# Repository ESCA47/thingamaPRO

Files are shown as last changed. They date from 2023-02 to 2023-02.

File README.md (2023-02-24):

# thingamaPRO

Order at your own risk, even i fuck up too often. Maybe poke at me for help but for the most part you are on your own if you do decide to order these.
This projecet was created to do the stupid thing I wanted and I got mine.

Goals of the project is to give as one to one a switch pro feel for ultimate on a gcc/phob interface. Anything past that is a nice bonus(melee or people calibrating to their own prefrences).

I highly implore you to calibrate either to the 3dp jig(and follow reccommended offsets or test for your own(except cstick that one is pretty bang on already)) or use some octo shell to calibrate before putting circle gates on these as otherwise the sticks will feel like dogshit and that's on you or whoever made you the thingamapro and you should yell at them.

Some things to absolutely not forget when ordering:

Front boards are 0.8mm thick and need gold finish to work at their best, ill probably chuck some of my bstock stuff for cheap on etsy if you dont want to drop 80 on 5 standard assembly boards

Main PCB is 1.2mm thick and you can do the regular finish as none are in the context of contact pads

Warnings aside the files I have supplied are only really a start since I personally dont want to say use this part or that part and tank the stuff i use over multiple designs so you will need a couple bit more brain cells to actually part out the boards properly. 

So for instance you will need to format the position file properly for jlc to be able to read it and also you need to double check all of the parts are on the right orientation(if someone wants to do this for me feel free since even i dont bother and i tinker with it too much). For the bom it should be descript enough that you can figure out the parts from looking at lcsc so have fun there.

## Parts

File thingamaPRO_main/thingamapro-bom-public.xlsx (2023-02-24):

Comment | Designator | Footprint | LCSC Part #（optional）
0.047u | C15 C16 C17 C18 C19 C20 | 0603_C | C1622
1u | C2 C13 | 0402_C
1u | C21 C31 C32 C33 | 0603_C
10u | C22 C23 | 0603_C | C19702
100n | C1 C9 C10 C11 | 0402_C
M7C | D1 | SOD-123 | C8598
1n4148 | D4 D5 D6 D7 | SOD-323
Schottky Barrier Diodes | D2, D8 | SOD-323 | C146335
Fuse | F1 | Fuse-1206 | C69680
Bottom Contact Surface Mount 0.5mm SMD,P=0.5mm FFC/FPC Connectors | J3
Shou Han Type-C 24P QCHT | J9 |  | C456013
Q_PMOS_GDS | Q1 | SOT-23 | C15127
Q_NMOS_GSD | Q2 Q3 | SOT-23 | C20917
10k | R1 R3 R5 | 0603_R | C25804
10k | R6 R7 R12 R13 | 0402_R
100R | R2 R4 | 0603_R | C22775
5.1k | R8 R9 | 0603_R
1K | R14 R19 | 0402_R
2k | R15 R16 R17 R18 | 0603_R | C22975
27R | R29, R30 | 0402_R
4pos smd switch 2.54mm 4 SMD-8P dip switch | sw1
Switch | S1 |  | C318884
MCP3002 | U6 U12 | SOIC-8
DRV5055A3QDBZR | U7 U8 U10 U11 | SOT-23
W25Q128JVS | U9 | SOIC-8
PRTR5V0U2X | U13 | SOT143B | C12333
XC6206PxxxMR | U14 | SOT-23 | C5446
RP2040 | U15 | RP2040-QFN-56 | C2040
12MHz SMD3213-3P | Y1 | Resonator_SMD_Murata_CSTxExxV-3Pin_3.0x1.1mm
6.3V 47uF | C3 | 3216

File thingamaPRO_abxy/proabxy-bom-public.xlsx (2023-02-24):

Comment | Designator | Footprint | LCSC Part #（optional）
Bottom Contact Surface Mount 0.5mm SMD,P=0.5mm FFC/FPC Connectors | J1
Switch | SW3, SW4, SW5, SW6
Clamshell 5 Double-sided Contact Surface Mount 0.5mm SMD,P=0.5mm FFC/FPC Connectors | J2
Bav70 | D1, D2

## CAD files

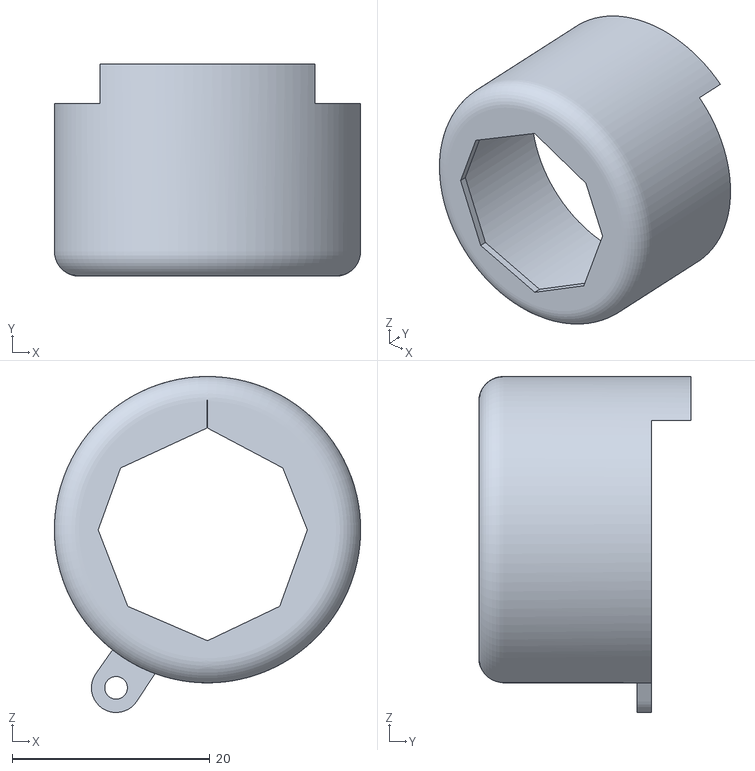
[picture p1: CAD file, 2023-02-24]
calibrationjig/mainjig.stl
31.0 x 21.5 x 34.0

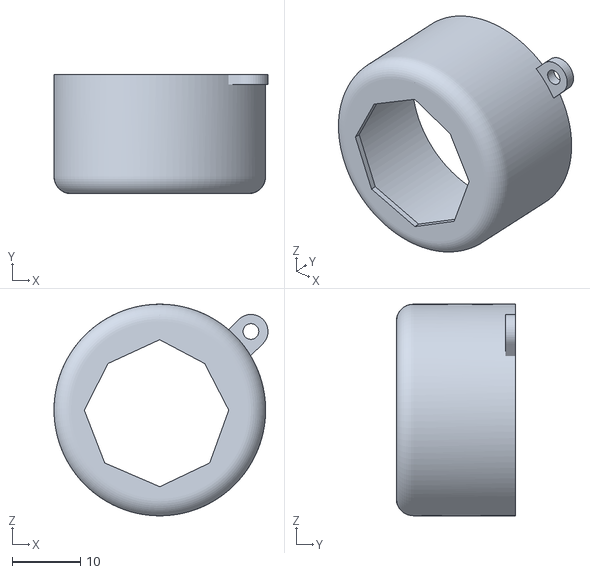
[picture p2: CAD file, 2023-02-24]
calibrationjig/cstickjig.stl
31.3 x 17.5 x 31.0

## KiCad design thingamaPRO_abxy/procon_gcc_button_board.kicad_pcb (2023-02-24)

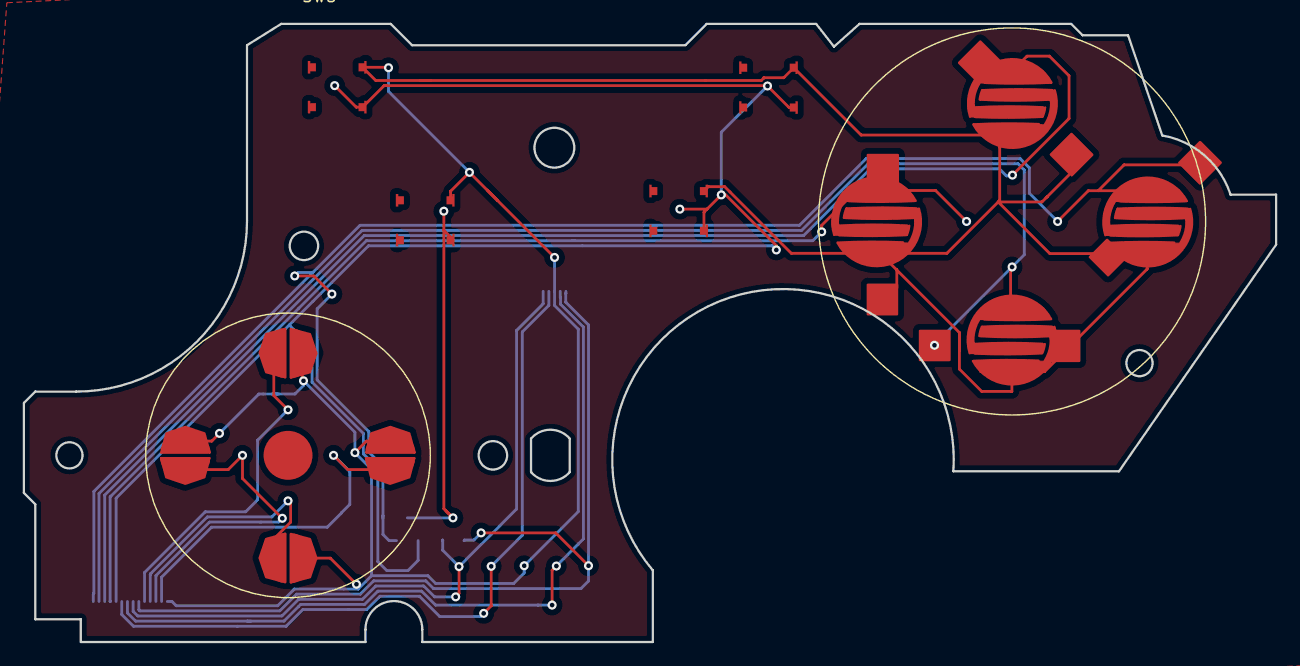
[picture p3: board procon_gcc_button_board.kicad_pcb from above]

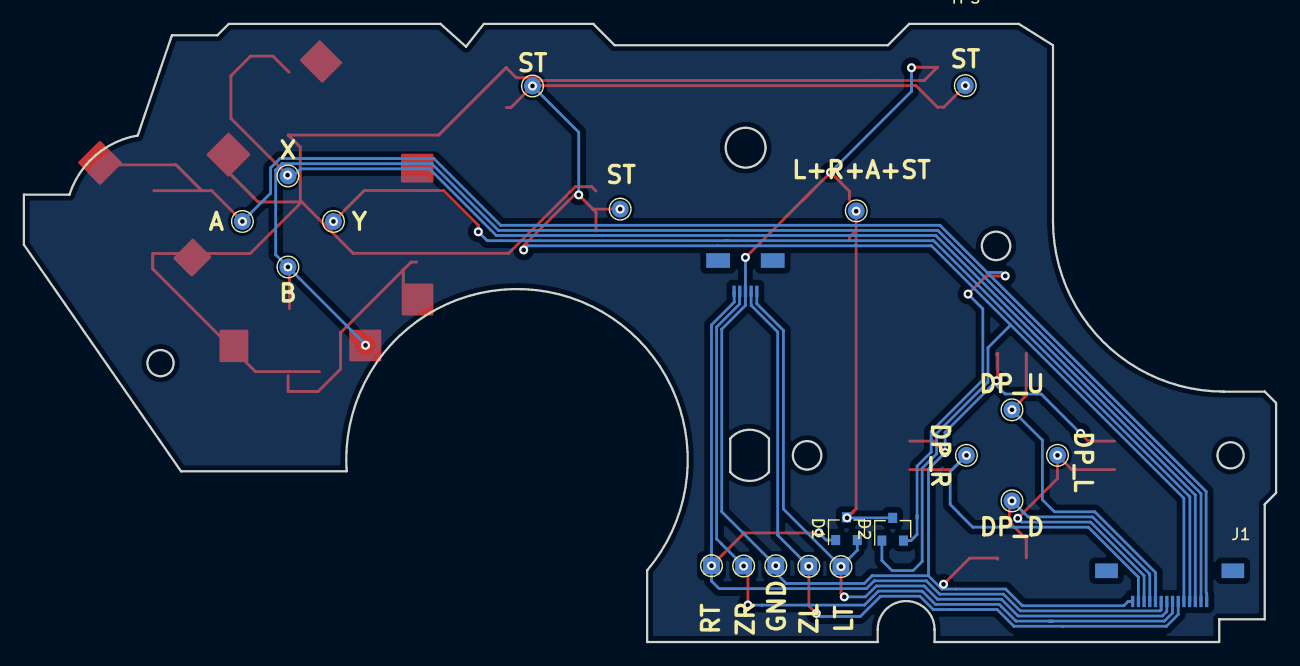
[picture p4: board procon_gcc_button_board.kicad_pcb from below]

Board: 2 copper layers, 110.0 x 54.3 mm, 31 parts (21 on the bottom side), 15 nets.

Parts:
D1, D2: BAV70; SOT-23
J1: Button Board; molex_5051101492_14P
J2: bumpers; molex_5051100592_5P
Ref**: Val**; ABXY_Contact_Omron_Switch
Ref**#2, Ref**#3, Ref**#4: Val**; ABXY_Contact_Omron_Switch
SW1: procon_abxy
SW2: procon_dpad
SW3, SW4, SW5, SW6: TL3315NF100Q; TL3315NFxxxQ
TP1, TP2, TP3, TP4, TP5, TP5#2, TP5#3, TP5#4, TP6, TP7, TP8, TP9, TP10, TP11, TP12, TP13, TP14: TestPoint; TestPoint_Pad_D1.5mm

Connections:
BB_BTN_A: D2.2 (A), J1.1, Ref**#4.2, SW1.1 (A), TP1.1
BB_BTN_B: J1.2, Ref**.2, SW1.2 (B), TP2.1
BB_BTN_DP_D: J1.11, SW2.3 (DP_D), TP11.1
BB_BTN_DP_L: J1.12, SW2.4 (DP_L), TP12.1
BB_BTN_DP_R: J1.13, SW2.2 (DP_R), TP13.1
BB_BTN_DP_U: J1.10, SW2.1 (DP_U), TP10.1
BB_BTN_LT: D1.2 (A), J1.8, J2.1, TP8.1
BB_BTN_RT: D1.1 (A), J1.9, J2.5, TP9.1
BB_BTN_ST: D2.1 (A), J1.5, SW3.1, SW5.1, SW6.1, TP5.1, TP5#2.1, TP5#3.1, TP5#4.1
BB_BTN_X: J1.3, SW1.4 (X), TP3.1
BB_BTN_Y: J1.4, SW1.3 (Y), TP4.1
BB_BTN_ZL: J1.6, J2.2, TP6.1
BB_BTN_ZR: J1.7, J2.4, TP7.1
GND: J1.14, J2.3, Ref**#2.2, Ref**#3.2, SW1.GND, SW2.GND, SW3.2, SW4.2, SW5.2, SW6.2, TP14.1
unnamed: D1.3 (K), D2.3 (K), SW4.1

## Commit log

2022-12-23 abxy board kicad files
    [procon_gcc_button_board-B_Courtyard.gbr, procon_gcc_button_board-B_Cu.gbr, procon_gcc_button_board-B_Fab.gbr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]
2022-12-23 main board+license
    [procon_gcc_main_pcb-B_Courtyard.gbr, procon_gcc_main_pcb-B_Cu.gbr, procon_gcc_main_pcb-B_Fab.gbr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]
2022-12-23 Delete proboss.zip
    wrong gerber that would cause issues i think
2023-02-24 front board changes
    [procon_gcc_button_board-B_Courtyard.gbr, procon_gcc_button_board-B_Cu.gbr, procon_gcc_button_board-B_Fab.gbr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]
2023-02-24 prod files removal
    [procon_gcc_button_board-B_Courtyard.gbr, procon_gcc_button_board-B_Cu.gbr, procon_gcc_button_board-B_Fab.gbr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]
2023-02-24 abxy board added
    [procon_gcc_button_board-B_Courtyard.gbr, procon_gcc_button_board-B_Cu.gbr, procon_gcc_button_board-B_Fab.gbr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]
2023-02-24 abxy board bom shell
    [proabxy-bom-public.xlsx]
2023-02-24 made calibration jig folder and documentation
2023-02-24 calibration jig stls
    steps will come eventually
    [cstickjig.stl, mainjig.stl]
2023-02-24 Main pcb+bom shell/pos files
    [procon_gcc_main_pcb-B_Courtyard.gbr, procon_gcc_main_pcb-B_Cu.gbr, procon_gcc_main_pcb-B_Fab.gbr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]
